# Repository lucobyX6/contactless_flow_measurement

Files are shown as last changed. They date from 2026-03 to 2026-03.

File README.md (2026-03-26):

# Projet recherche 2026 - Capteur de débit d'eau sans contact

Ce projet s'inscrit dans le cursus d'ingénieur ISMIN (_Ingénieur Systèmes Microélectronique et Informatique_). 

## Auteurs
- École des Mines de Saint-Étienne - Étudiant ISMIN : Lucas VINCENT
- École des Mines de Saint-Étienne - Étudiant ISMIN (Double-diplôme) : Reem AL HADDAD

## Contexte

En France, 12% de l'irrigation est réalisée par irrigation gravitaire. Ce procédé repose sur un réseau de canaux de tailles diverses qui distribue l'eau grâce à la différence d'altitude entre l'amont et l'aval. Cette technique ancestrale a notamment permis d'irriguer des terres arides dans le sud de la France, comme la *La Plaine de La Crau*. 

Le dérèglement climatique nous impose de repenser notre utilisation de l’eau. De manière à raisonner son usage et mettre en place les mesures adaptés. Ainsi, il est nécessaire d'établir une surveillance préalable de ces canaux. Pour obtenir le maximum d'informations à l'échelle la plus large possible. Les chercheurs déploient des réseaux de capteurs intelligents le long des cours d'eau.

Traditionnellement, les systèmes employés sont mécaniques et immergés. Cependant, les canaux sont des
milieux à ciel ouvert où transitent une multitude de débris, dont des branches, des feuilles ou des sédiments. Ces perturbations rendent les capteurs immergés peu efficaces, car elles peuvent les bloquer ou les endommager. 

L'alternative actuelle est d'utiliser des capteurs basés sur la technologie radar, entre 10 et 80GHz. Ces derniers sont peu sensibles à la qualité de l'eau ou la présence d'algues et de sédiments. Ils admettent aussi une excellente précision et un faible entretien. Cependant, les objets en surface ou la turbulence des eaux affectent la fiabilité des résultat. De plus, le prix de ces capteurs pouvant atteindre plusieurs milliers d'euros, est un frein à leur déploiement à grande échelle. 

## Capteur `Time-of-flight`

Le projet est une exploration de l'intérêt d'un capteur `Time-of-flight` (TOF) dans l'acquisition du débit d'eau pour les canaux. Ce capteur est équipé d'un émetteur (Tx) et d'un récepteur (Rx). L'émetteur émet un signal infrarouge, qui est réfléchi par la surface, puis retourne dans le récepteur. La carte d'acquisition intégrée analyse la durée entre l'envoi et la réception et à partir de la vitesse de la lumière, constante dans l'air, elle déduit la distance entre le capteur et l'obstacle.     

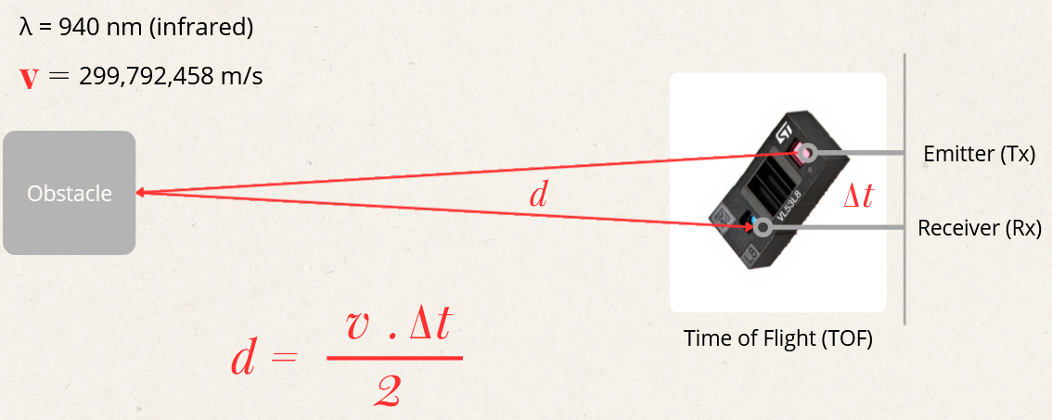
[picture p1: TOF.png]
Illustration of how the time-of-flight sensor works Illustration du fonctionnement du capteur Time-of-flight


Il existe deux types de capteurs `TOF` : 
- Simple : Acquisition d'un unique point.
- Multizone : Acquisition d'une matrice de points.

Nous avons utilisé le `TOF Multizone`, car il permet l'acquisition d'un échantillon de surface, plutôt qu'un unique point.

Sur le papier, il représente une alternative peu coûteuse financièrement et énergétiquement par rapport aux solutions à base de technologies radars actuellement développées. Cependant, nos recherches révèlent que son usage dans le milieu des canaux est **complexe**. 

Ce travail est inspiré de la vidéo [Turn a Time-of-Flight Sensor into a 3D Scanner](https://www.youtube.com/watch?v=s32OUzhjf4U). 

**Matériel utilisé :**
- Carte `Nucleo - STM32 L476RG`
- Capteur TOF Multizone `VL53L5CX` avec module SATEL
- Servomoteur `Microservo 9g`

| Pin | Fonction |
| --- | --- |
| PB9 | SDA - TOF |
| PB8 | SCL - TOF |
| PB0 | LPN - TOF |
| GND | I2C - RST |
| PB0 | LPN - TOF |
| PC0 | PWR_EN - TOF |
| 5V | AVDD |
| 3.3V | IOVDD |
| PB10 | Servo - PWM |

**Documentation :**  \
[1] VL53L8CX Datasheet, ST Microelectronics, 22 December 2022 . [En ligne]. Disponible suivant ce [lien](https://www.st.com/resource/en/datasheet/vl53l8cx.pdf)

[2] SparkFun_VL53L5CX_Library, SparkFun Electronics, No publication date. [En ligne]. Disponible suivant ce [lien](https://github.com/sparkfun/SparkFun_VL53L5CX_Arduino_Library)

[3] NUCLEO-L476RG Pinout, ST Microelectronics, No publication date. [En ligne]. Disponible suivant ce [lien](https://os.mbed.com/platforms/ST-Nucleo-L476RG/#overview)

## Arborescence du projet

Le projet est découpé en deux parties, l'étude de la réflectance de l'eau et l'acquisition et le traitement de données en temps réel. 

- ./0_Water_reflexion : Expériences sur la réflectance de l'eau. 
- ./1_Real_time : Acquisition en temps réel des données du capteurs, traitement et affichage dynamique. 
- ./2_3D_Object : Ensemble des modélisations 3D réalisées en support du projet. 
- ./3_Academic_documents : Rapport et diaporama en anglais détaillant le projet. 

Au vu de la durée du projet, nous avons préféré utiliser `PlatformIO` (similaire à `ArduinoIDE`) plutôt que `STM32 CubeIDE`. Le code est en `C++` et utilise la bibliothèque clef-en-main `SparkFun_VL53L5CX_Library` basée sur la bibliothèque de ST Microelectronics, [x-cube-tof1](https://github.com/STMicroelectronics/x-cube-tof1).  

## Phases du projet

**Phase 1 : Modélisation de la surface de l'eau**

La première approche a été d'essayer de modéliser la surface de l'eau. Le capteur est placé à un peu plus d'un mètre de la surface, de tel sorte que tous ses rayons soient réfléchis exclusivement par l'eau. Toutes les 10ms, il réalise une acquisition qui correpond à un échantillon de la surface de l'eau à l'instant t. En comparant les échantillons, on peut déduire une variation de hauteur et étudier l'aspect de la surface, potentiellement lié à la vitesse de l'eau. 

Malheureusement, nos expériences sur la réflectance de l'eau ont révélé qu'elle ne réfléchissait pas les infrarouges.  

**Phase 2 : Détection d'objets en surface**

L'eau absorbe l'intégralité des rayons infrarouges émis par le capteur. Ainsi, les objets en surface qui sont eux potentiellement réfléchissants peuvent être plus facilement détecté. Cela revient à placer un objet blanc sur une feuille noire. L'étude des mouvements des objets flottants, branches, feuilles et écorces serait une solution pour connaître la vitesse de l'eau en surface (dans un milieu où le vent est négligeable). 

Malheureusement, la précision du capteur décroit avec la distance et la résolution diminue avec l'éloignement. Ces deux phénomènes couplés rendent presque impossible la détection d'un objet à un mètre de distance. 

**Phase 3 : Mise en rotation du capteur**

Pour permettre la détection précise d'objet, il faut obtenir des points d'acquisition plus proche et augmenter leur nombre. L'utilisation de plusieurs capteurs risque de provoquer des interférences optiques qui peuvent impacter la qualité des résultats. La solution la plus simple serait de placer le capteur sur un axe en rotation, à l'aide d'un moteur asservi. Le pas du moteur dicterait alors la résolution. Cette méthode pourrait s'émanciper du capteur multizone 8x8 pour revenir sur un TOF simple.     

Cette phase n'a pas été achevée et reste à approfondir. 

## Conclusions

- L'eau absorbe les ondes infrarouges émisent par le capteur. Cette absorption est d'autant plus présente que le volume d'eau est important. Dans un canal, l'absorption est totale empêchant la prise de mesure à la surface de l'eau. Cette problématique oblige à détecter des objets en surface pour mesurer leur vitesse, plutôt que la surface de l'eau. 

- La résolution du capteur dépend de la distance. La zone d'émission est une pyramide d'angle 45°. Ainsi, plus la distance est importante, plus la distance entre deux points d'aquisition est grande. De plus, la précision décroit avec la distance. Ces deux phénomènes cumulés impactent la capacité à détecter des formes ou un objet à moyenne (1m) ou longue distance (2m). 

- Si le capteur est placé sur un moteur asservi, comme un servomoteur, il peut acquérir un plus grand nombre de points proches les uns des autres. Cette méthode permet d'améliorer la résolution et peut donc potentiellement corriger la problématique identifiée précédemment. 

## Ouverture 

Il existe une technologie similaire au TOF en rotation nommé le LiDAR (light detection and ranging). Ce dernier admet une meilleure résolution, permet une rotation à 360° avec une haute fréquence d'acquisition et est une technologie déjà fortement déployée dans l'industrie, notamment en navigation autonome. 

Cette piste semble donc être une nouvelle voie prometteuse d'analyse. Le capteur pourrait être placé au dessus du canal. Pour obtenir la vitesse de l'eau en surface, il mesurerait la vitesse des feuilles et branchages flottants. Pour mesurer la hauteur d'eau, il étudierait la berge et chercherait un saut de réflectance entre la béton et l'eau.

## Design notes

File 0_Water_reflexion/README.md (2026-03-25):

# Étude de la réflectivité de l'eau

## Organisation du répertoire : 

Le répertoire du projet est constitué de la manière suivante :
- ./0_Programs : Contient l'ensemble des programmes python et C++. 
- ./1_Pictures : Contient les résultats des expériences.
- ./2_Data : Contient les donneés brutes récupérées par durant les expériences. 

## Expériences :

L'objectif de ces expériences est de mesurer la **réflectivité de l'eau** vis à vis du rayon infrarouge émis par le capteur Tof. Deux expériences ont été réalisé, la première a permi de découvrir l'impact du volume d'eau sur la réflectivité et la seconde la réflectivité dans un cas réel, directement sur le canal. 

Le code `Mean_on_reflectance_calculation.cpp` est le code envoyé dans le carte *STM32 L476RG* pour la première expérience. Il suffit pour l'utiliser de copier son contenu dans le fichier `main.cpp` de votre projet.    

La seconde expérience nécessite l'usage du code `Mean_on_distance_calculation.cpp`.

### Expérience 1 - Test de réflectivité dans un récipient

L'objectif de cette expérience est d'obtenir un premier aperçu de la variation de réflectivité induite par l'eau, en fonction du volume. Pour la réaliser, le capteur a été positionné verticalement au dessus d'un récipient rempli d'eau, de tel sorte que les rayons lumineux se disperse le moins possible et atteignent tous la surface de l'eau.   

**Choix du récipient :**

Le premier récipient utilisé était une casserole pour sa praticité d'usage et son volume. Cependant, le capteur renvoyait des valeurs étrangements faible, peu importe la quantité d'eau. Après comparaison avec un récipient en verre, il s'est avéré que la casserole fonctionnait comme un guide d'ondes pour les rayons infrarouges. Pour écarter ce problème, l'expérience a été réalisée avec un bol en verre. 

**Acquisition :**

La carte électronique génère au bout d'une dizaine de secondes une liste de 64 valeurs.  Chaque valeur est la moyenne des résultats pour un point d'acquisition sur 10s. Les résultats sont stockées dans le dossier `./2_Data`.   

**Résultats :**

Les résultats précédents sont traités par le programme python `E1_display_water_reflexion_results.py`. Ce dernier génère à partir de ces données des matrices. Elles sont stockées dans le dossier `./1_Pictures` avec le préfixe `E1_`. Chaque carré est une cellule d'acquisition du récepteur.   

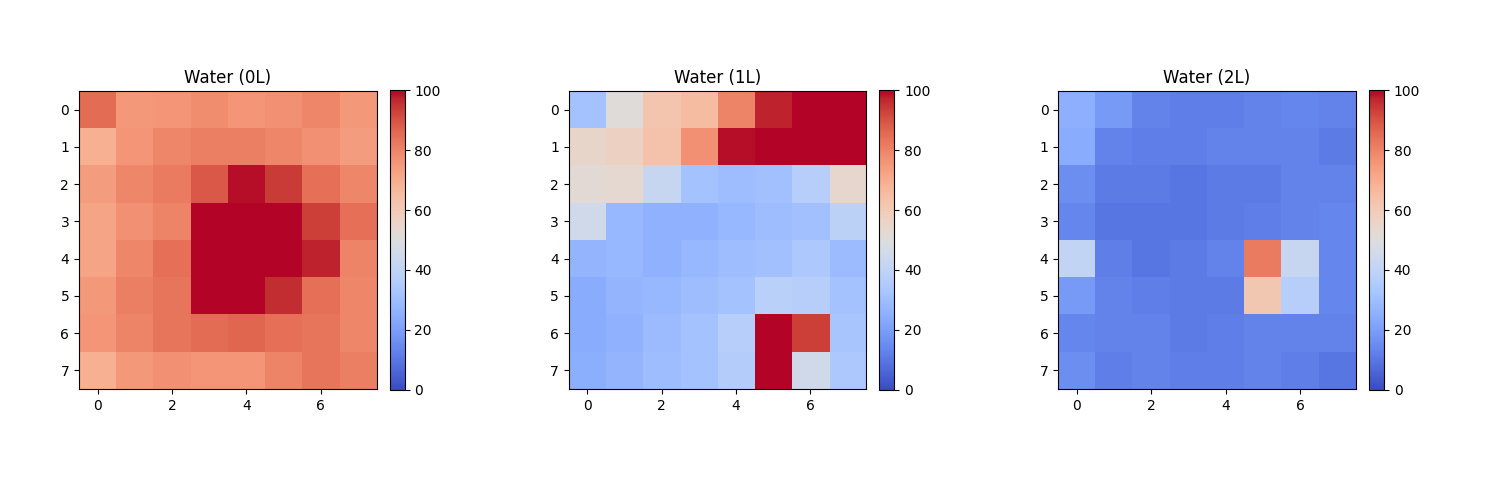
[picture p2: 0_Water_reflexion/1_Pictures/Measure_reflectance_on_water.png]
Results of the reflectivity measurement experiment for 0L, 1L and 2L of water in the container. Résultats de l'expérience de mesure de la réflectivité pour 0L, 1L et 2L d'eau dans le récipient.


La réflectance s'exprime en pourcentage et représente la part d'énergie qui a été réfléchie par la surface et qui est retournée vers la cellule d'acquisition. On remarque qu'**initialement**, la **réflectance est quasi-totale**. Néanmoins, dès qu'on **ajoute de l'eau** cette dernière chute jusqu'à être **quasiment nulle**.   

_Données associées :_ 
- reflectance_0.5L_waveguide_issue.txt
- reflectance_2L_waveguide_issue.txt
- reflectance_4L_waveguide_issue.txt
- reflectance_no_water.txt
- reflectance_1L.txt
- reflectance_2L.txt

### Expérience 2 - Test de réflectivité dans le canal

**Environnement de test :**

Les résultats de l'expérience précédente ont révélé que plus il y avait d'eau, plus la réflectivité était faible. Cette deuxième expérience vise à étudier la réflectance en milieu réel. Elle a été réalisé sur le **Canal de Provence** ([43.441339, 5.488827](https://www.openstreetmap.org/search?lat=43.441339&lon=5.488827&zoom=19#map=19/43.441339/5.488827)) à proximité de l'école. 

Le capteur a été disposé sur l'une des berges, tête en direction de l'eau. Il était à moins d'un mètre de la surface. La mesure a permi d'établir la matrice suivante. 

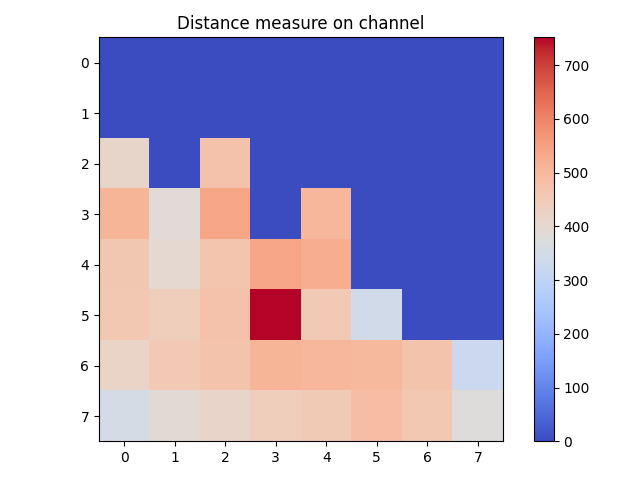
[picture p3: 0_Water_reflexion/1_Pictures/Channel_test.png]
Results of the measurement experiment on the channel. Résultat de l'expérience de mesure sur le canal.


Les résultats sont traités par le programme python `E2_test_on_channel.py`.

**Observations :**

La moitié des rayons, ici la partie basse de l'image, se sont réfléchis sur le parapet en béton du canal. La réflectance a été suffisante pour qu'ils renvoient une distance chiffrée. La seconde partie des rayons se sont réfléchis sur l'eau. Le capteur a transmis pour chacune de ces positions, une valeur 0. 

Ce comportement a lieu si aucun rayon ne revient en direction du capteur, car la surface est trop lointaine, ou dans le cas, où la réflectance est nulle. Dans le cas de cette expérience, le capteur est à moins d'un mètre de la surface acqueuse. Ainsi, l'eau a absorbé tous les rayons.

_Données associées :_ 
- channel_water_test.txt
- sky_test.txt

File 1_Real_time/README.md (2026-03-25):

# Acquisition et traitement des données du capteur en temps réel

## Organisation du répertoire : 

Le répertoire du projet est constitué de la manière suivante :

. \
├── 0_Static : Contient les pré-codes pour tester les fonctionnalités sur des données statiques avant l'implémentation dynamique. \
│   ├── 0_Programs : Algorithme C++ et Python \
│   ├── 1_Data : Données récoltées pour tester les foncionnalités \
│   └── 2_Pictures : Matrices résultats. \
├── 1_Dynamic : Contient les codes d'acquisition et de traitement en temps réel. \
│   ├── 0_Without_obj_detect : Acquisition en temps réel et affichage sans traitement dans une matrice 3D. \
│   ├── 1_With_obj_detect : Acquisition en temps réel, identification des objets puis affichage dans une matrice 3D. \
│   ├── 2_With_distances_between_points : Acquisition en temps réel, identification des objets puis affichage dans une matrice 3D en prenant en considération la résolution. \
│   └── 3_With_rotation : Acquisition en temps réel, identification des objets puis affichage dans une matrice 3D avec la rotation autour d'un axe.

## Section statique

**Algorithmes :**
- `print_values.py` : Lit le fichier de données et affiche les valeurs dans une matrice 8x8.  
- `detect_object.py` : Détecte les objets présents dans les données à l'aide d'une heuristique. 
- `detect_movement.py` : Détecte les objets et leur barycentre à l'aide d'une heuristique.  

Le code `get_mean_distances.cpp` est le code envoyé dans le carte *STM32 L476RG* pour récupérer les données nécesaires aux algorithmes de la section. Il suffit pour l'utiliser de copier son contenu dans le fichier `main.cpp` de votre projet. 

**L'impact de la distance sur la résolution :**

Les nouvelles fonctionnalités, comme l'affichage 3D et la détection d'objets sont initialement développées et testés sur des données que nous avons récoltés. Le dossier `Distance_problem` contient les mesures receuillies à différentes distances d'objets. L'objectif était d'étudier l'impact de la résolution sur la détection. 

Plus l'objet **est lointain**, plus **la résolution est faible**, car la zone d'émission est plus grande, ce qui peut être assimilé à un écartement des points d'acquisition.  

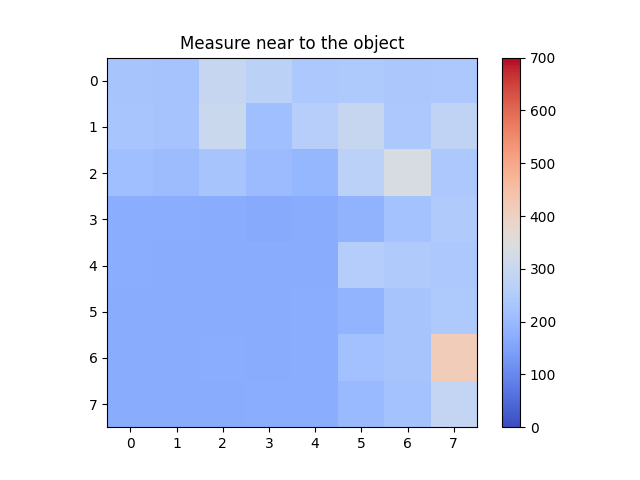
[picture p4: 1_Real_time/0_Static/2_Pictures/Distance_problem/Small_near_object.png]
Measure near to the objet at 20cm away. Mesure d'un objet à une vingtaine de centimètres.


Cette première capture réalisée à une vingtaine de centimètres de l'objet. On y détecte aisément la forme de l'objet de la cellule 3,0 à la cellule 7,4.  

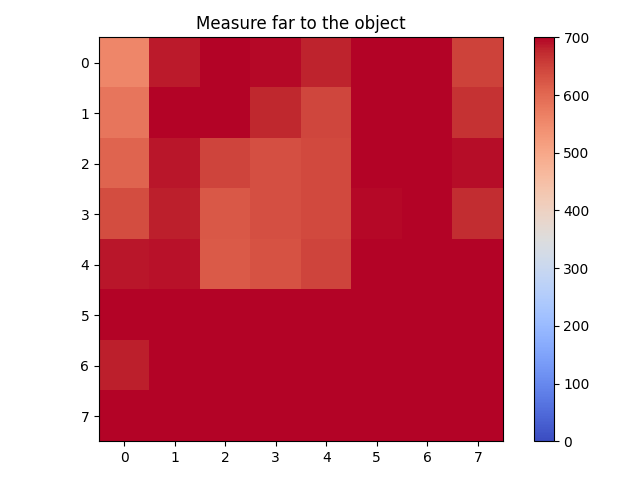
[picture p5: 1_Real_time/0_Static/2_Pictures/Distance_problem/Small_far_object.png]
Measure far to the objet at 1m away. Mesure d'un objet à un peu plus d'un mètre.


Néanmoins, sur cette seconde illustration prise à un peu plus d'un mètre de l'objet, il est impossible de le détecter. 

Le dossier `Objects_movement` contient les données pour la détection d'objets et de barycentre. Initialement, l'algorithme récupère les valeurs brutes de distances (voir première image). À partir d'une heuristique simple, il détecte pour chaque point ses voisins et lui attribue une valeur. Cette valeur désigne son groupe potentiel. Les groupes sont ensuite affichés avec des couleurs (voir deuxième image). Un autre algorithme basé sur la même heuristique calcule le barycentre de chacun de ces groupes. En comparant la position des barycentres pour deux captures proches, on peut déduire la vitesse de l'objet.    

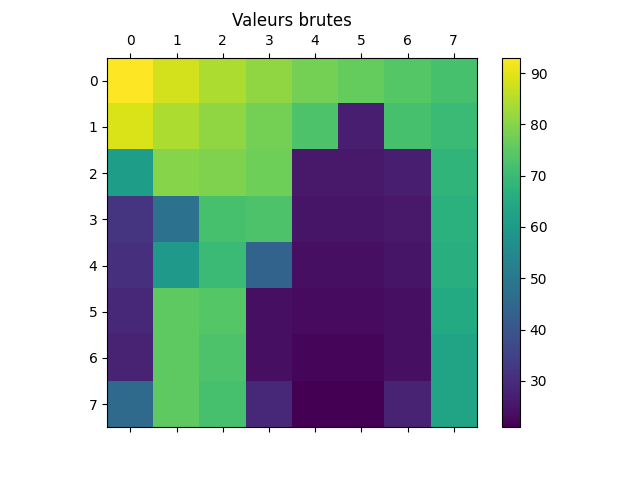
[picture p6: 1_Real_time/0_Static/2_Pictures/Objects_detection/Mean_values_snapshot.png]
Intial value calculated by sensor. Valeur initialement récupérée par le capteur.


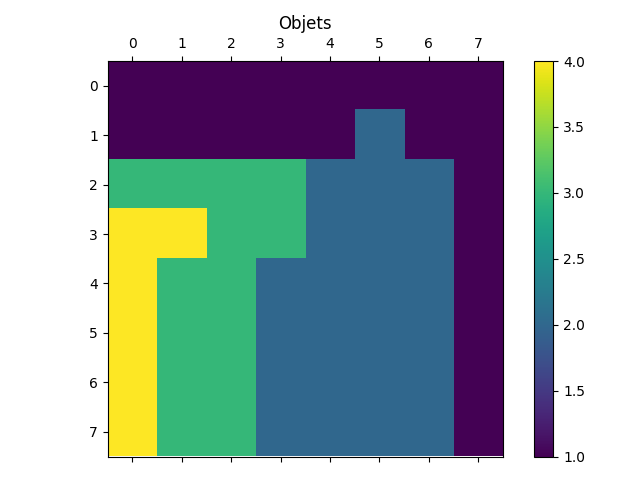
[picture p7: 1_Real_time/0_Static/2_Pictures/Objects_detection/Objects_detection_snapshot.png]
Calculated groups by the algorithm. Groupes calculés par l'algorithme.


## Section dynamique

Cette section est l'application sur un flux de données temps réel des opérations de la section statique. Chaque algorithme `C++` renvoit les valeurs nécessaires à l'algorithme `Python` lié. Cet algorithme affiche les valeurs dynamiquement dans une matrice 3D. L'échelle est en milimètre pour l'axe z et en identifiant de cellules pour l'axe x et y (sauf à partir du dossier `/2_With_distances_between_points`).  

**Dossiers :**
- ./0_Without_obj_detect : Récupération des données de la `carte ST L476RG`, réflectances ou distances et affichage en 3D. 
- ./1_With_obj_detect :  Récupération des données (distances mesurées) de la `carte ST L476RG`, traitement pour détecter les objets et affichage en 3D.  
- ./2_With_distances_between_points : Récupération des données (distances mesurées), traitement pour détecter les objets et affichage en prenant en considération la distance entre les points d'acquisition (répartition homogène).   
- ./3_With_rotation : Identique à précédemment, mais à l'aide d'une matrice de rotation le capteur tourne dans l'espace. 

**Cas particulier de `1_With_obj_detect` :**

Pour utiliser le code Python `real_time_display_obj.py`, il convient d'utiliser le code C++ `real_time_acquisition.cpp` du dossier précédent. Le code C++ `3D_with_detection_objects.cpp` est une convertion du code Python en C++ pour détecter les objets directement sur la carte sans nécessiter un ordinateur. Le code Python `real_time_display_obj_from_C.py` permet d'afficher les résultats de ce code C++.   

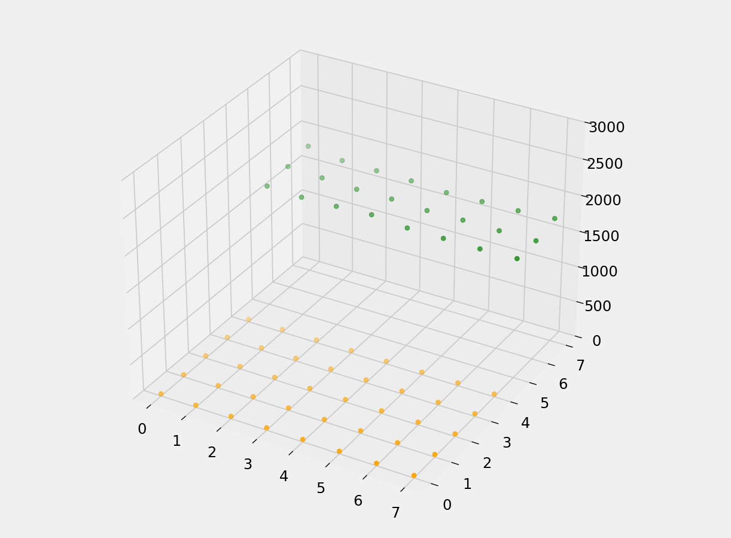
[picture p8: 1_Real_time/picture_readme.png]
Object detection result and 3D display Résultat de la détection d'objet et affichage dans l'espace


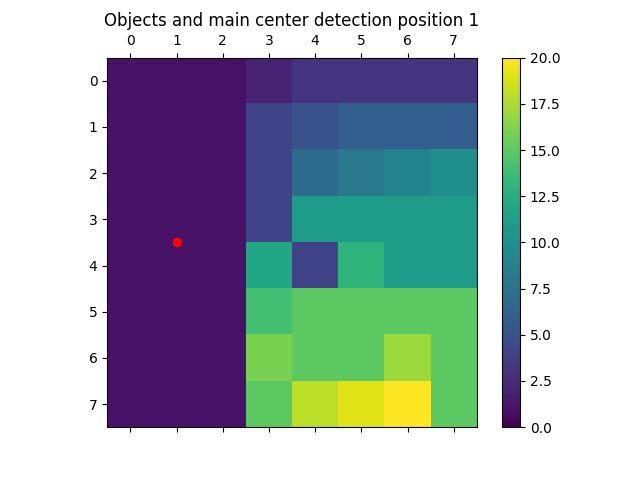
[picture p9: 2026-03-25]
1_Real_time/0_Static/2_Pictures/Objects_movement/move_pos1.png

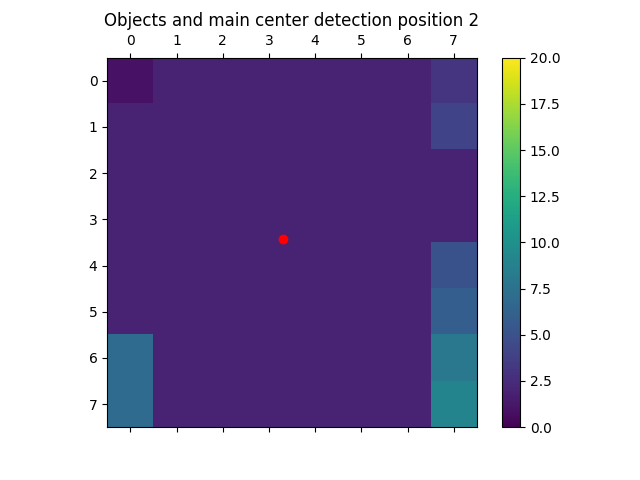
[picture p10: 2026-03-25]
1_Real_time/0_Static/2_Pictures/Objects_movement/move_pos2.png

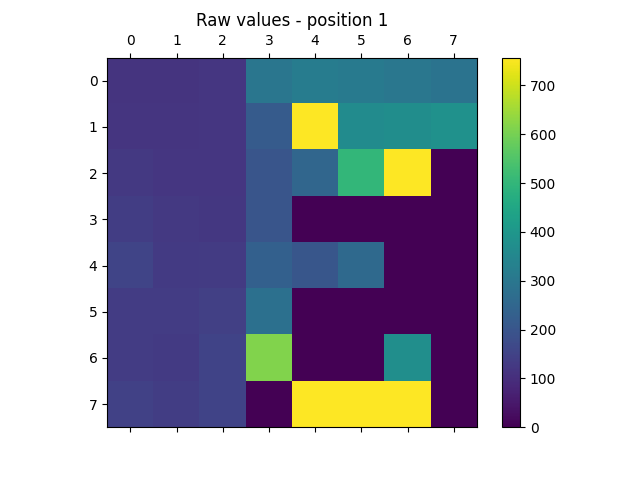
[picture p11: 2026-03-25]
1_Real_time/0_Static/2_Pictures/Objects_movement/raw_pos1.png

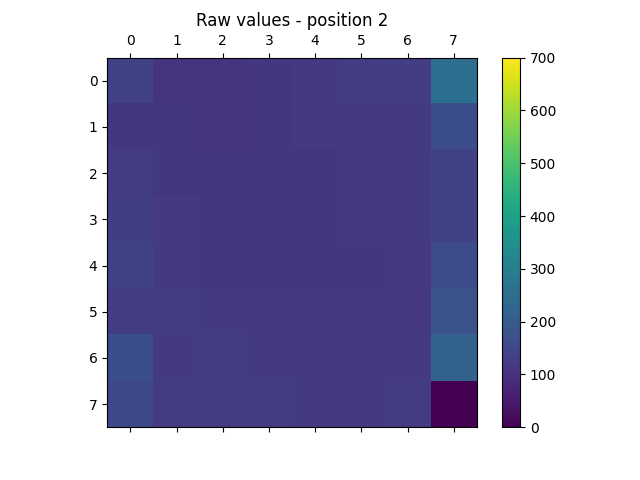
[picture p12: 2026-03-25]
1_Real_time/0_Static/2_Pictures/Objects_movement/raw_pos2.png

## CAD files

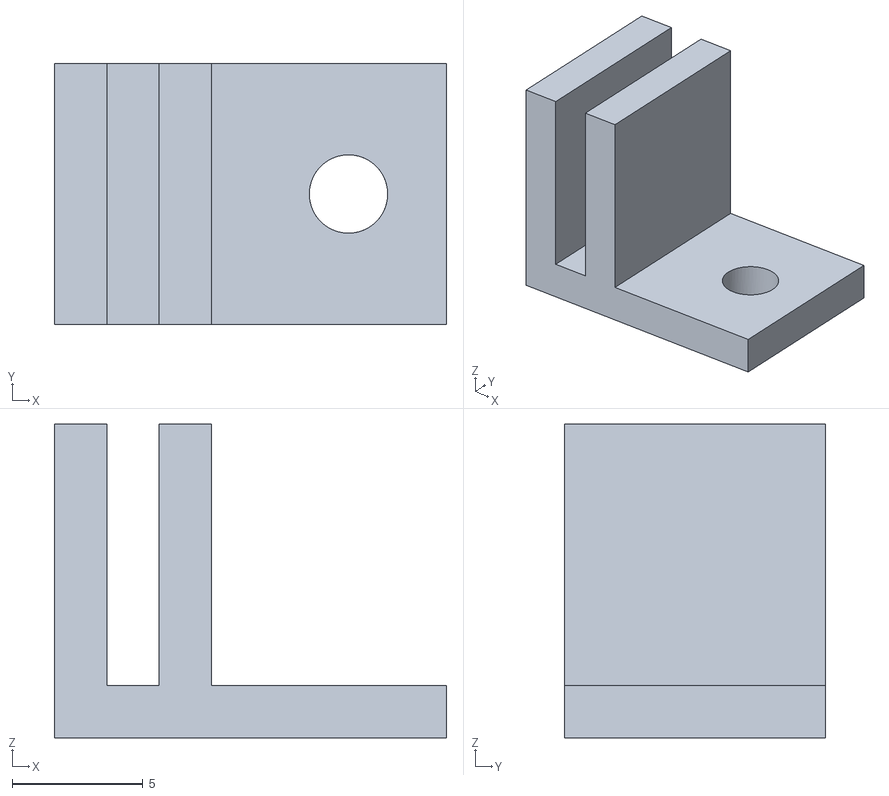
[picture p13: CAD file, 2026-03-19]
2_3D_Object/STL/TOF_holder.stl
15.0 x 10.0 x 12.0

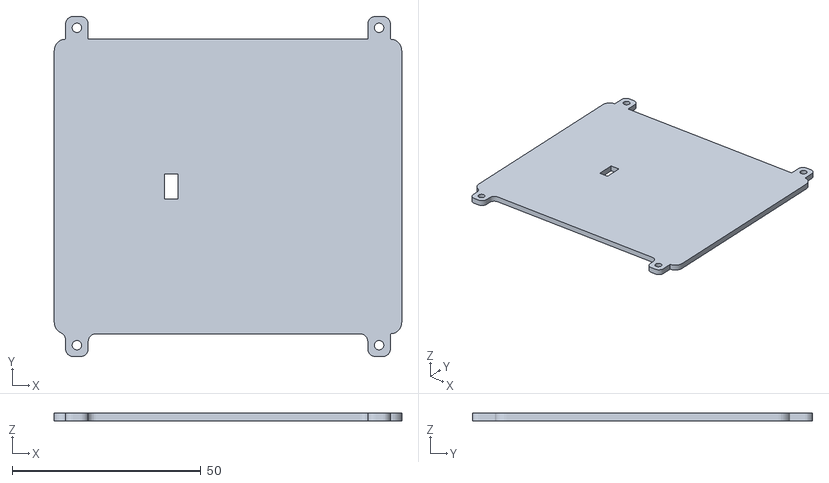
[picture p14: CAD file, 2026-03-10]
2_3D_Object/STL/TOF_Box_base.stl
92.0 x 90.0 x 2.00

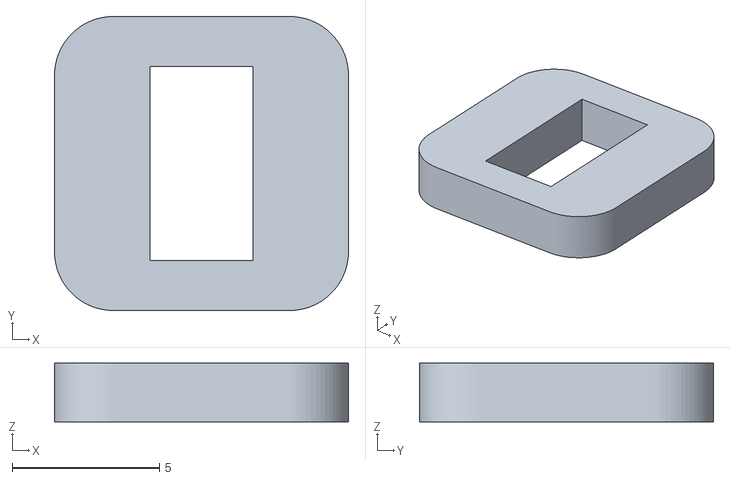
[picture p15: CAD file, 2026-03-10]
2_3D_Object/STL/Test_TOF_hole.stl
10.0 x 10.0 x 2.00

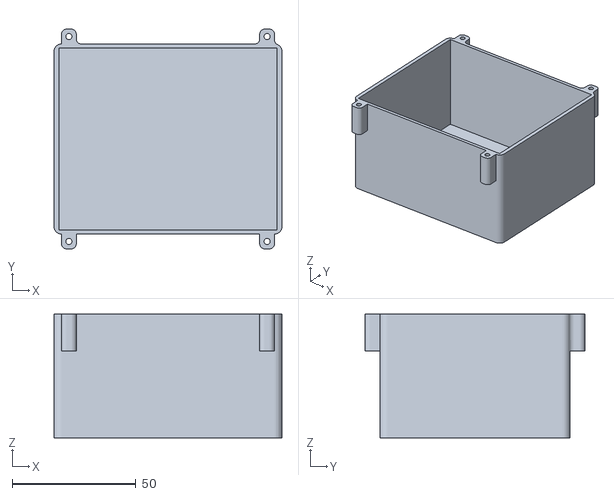
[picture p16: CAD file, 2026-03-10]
2_3D_Object/STL/STM32_Box_base.stl
92.0 x 88.7 x 50.0

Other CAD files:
2_3D_Object/IPT/OldVersions/TOF_holder.0001.ipt
2_3D_Object/IPT/STM32_Box_base.ipt
2_3D_Object/IPT/TOF_Box_base.ipt
2_3D_Object/IPT/TOF_holder.ipt
2_3D_Object/IPT/Test_TOF_hole.ipt

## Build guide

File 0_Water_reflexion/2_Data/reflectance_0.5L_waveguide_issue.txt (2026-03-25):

0, 0: 4
0, 1: 4
0, 2: 6
0, 3: 3
0, 4: 5
0, 5: 3
0, 6: 6
0, 7: 6
1, 0: 5
1, 1: 5
1, 2: 4
1, 3: 3
1, 4: 3
1, 5: 2
1, 6: 4
1, 7: 6
2, 0: 52
2, 1: 6
2, 2: 7
2, 3: 3
2, 4: 3
2, 5: 5
2, 6: 4
2, 7: 6
3, 0: 82
3, 1: 6
3, 2: 5
3, 3: 3
3, 4: 2
3, 5: 2
3, 6: 5
3, 7: 5
4, 0: 5
4, 1: 5
4, 2: 4
4, 3: 3
4, 4: 5
4, 5: 3
4, 6: 4
4, 7: 8
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

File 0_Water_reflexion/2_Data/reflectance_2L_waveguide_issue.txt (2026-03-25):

0, 0: 1
0, 1: 3
0, 2: 2
0, 3: 2
0, 4: 2
0, 5: 2
0, 6: 2
0, 7: 2
1, 0: 1
1, 1: 2
1, 2: 2
1, 3: 2
1, 4: 2
1, 5: 2
1, 6: 2
1, 7: 5
2, 0: 1
2, 1: 2
2, 2: 2
2, 3: 2
2, 4: 3
2, 5: 3
2, 6: 6
2, 7: 2
3, 0: 1
3, 1: 2
3, 2: 2
3, 3: 2
3, 4: 19
3, 5: 49
3, 6: 3
3, 7: 2
4, 0: 1
4, 1: 4
4, 2: 2
4, 3: 2
4, 4: 3
4, 5: 69
4, 6: 8
4, 7: 3
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

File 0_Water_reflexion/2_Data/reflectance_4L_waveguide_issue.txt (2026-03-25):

0, 0: 0
0, 1: 0
0, 2: 0
0, 3: 0
0, 4: 0
0, 5: 0
0, 6: 0
0, 7: 11
1, 0: 1
1, 1: 1
1, 2: 3
1, 3: 1
1, 4: 0
1, 5: 0
1, 6: 0
1, 7: 0
2, 0: 32
2, 1: 11
2, 2: 1
2, 3: 1
2, 4: 0
2, 5: 0
2, 6: 2
2, 7: 0
3, 0: 73
3, 1: 2
3, 2: 1
3, 3: 0
3, 4: 0
3, 5: 0
3, 6: 0
3, 7: 0
4, 0: 1
4, 1: 3
4, 2: 1
4, 3: 0
4, 4: 0
4, 5: 0
4, 6: 0
4, 7: 3
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

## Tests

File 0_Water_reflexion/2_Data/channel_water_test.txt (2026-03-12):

0, 0: 0
0, 1: 0
0, 2: 0
0, 3: 0
0, 4: 0
0, 5: 0
0, 6: 0
0, 7: 0
1, 0: 0
1, 1: 0
1, 2: 0
1, 3: 0
1, 4: 0
1, 5: 0
1, 6: 0
1, 7: 0
2, 0: 413
2, 1: 0
2, 2: 475
2, 3: 0
2, 4: 0
2, 5: 0
2, 6: 0
2, 7: 0
3, 0: 506
3, 1: 388
3, 2: 539
3, 3: 0
3, 4: 500
3, 5: 0
3, 6: 0
3, 7: 0
4, 0: 461
4, 1: 399
4, 2: 466
4, 3: 538
4, 4: 525
4, 5: 0
4, 6: 0
4, 7: 0
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

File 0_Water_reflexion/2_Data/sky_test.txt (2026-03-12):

0, 0: 0
 0, 1: 0
 0, 2: 0
 0, 3: 0
 0, 4: 0
 0, 5: 0
 0, 6: 0
 0, 7: 0
 1, 0: 0
 1, 1: 0
 1, 2: 0
 1, 3: 0
 1, 4: 0
 1, 5: 0
 1, 6: 0
 1, 7: 0
 2, 0: 0
 2, 1: 0
 2, 2: 0
 2, 3: 0
 2, 4: 0
 2, 5: 0
 2, 6: 0
 2, 7: 0
 3, 0: 0
 3, 1: 0
 3, 2: 0
 3, 3: 0
 3, 4: 0
 3, 5: 0
 3, 6: 0
 3, 7: 0
 4, 0: 0
 4, 1: 0
 4, 2: 0
 4, 3: 0
 4, 4: 0
 4, 5: 0
 4, 6: 0
 4, 7: 0
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

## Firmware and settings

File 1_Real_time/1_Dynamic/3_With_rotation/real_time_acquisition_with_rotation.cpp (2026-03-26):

#include <Wire.h>
#include <SparkFun_VL53L5CX_Library.h>
#include <Servo.h>

// Pin definitions
#define SDA_PIN PB9
#define SCl_PIN PB8
#define LPN_PIN PB0
#define PWR_EN_PIN PC0
#define PWM_SERVO_PIN PB10

// VL53L5CX ToF sensor instance
SparkFun_VL53L5CX sensor;
VL53L5CX_ResultsData measurementData;

// DF9GMS servo motor instance
Servo servo_tof;

// I2C speed - use 1MHz for fast data transfer
#define I2C_SPEED 1000000

// Angle °
int angle =0;
int direction =1;

void setup() {
  Serial.begin(115200); // COM 115200 bauds
  delay(3000); // Waiting for serial monitor

  Serial.println("[INFO] Initializing pins");

  // Enable power by setting PWR_EN HIGH 
  pinMode(PWR_EN_PIN, OUTPUT);
  digitalWrite(PWR_EN_PIN, HIGH);
  delay(10);

  // Enable I2C on sensor by setting LPn HIGH
  pinMode(LPN_PIN, OUTPUT);
  digitalWrite(LPN_PIN, HIGH);
  delay(10);

  // Servomotor
  servo_tof.attach(PWM_SERVO_PIN); 
  Serial.println("[INFO] Servo ready");

  // Initialize I2C with specified pins and speed
  Wire.begin();
  Wire.setClock(I2C_SPEED);

  Serial.println("[INFO] I2C ready");

  // Initialize sensor
  if (!sensor.begin()) {
    Serial.println("[ERROR] Sensor init failed");
    while (1) {
      delay(100);
    }
  }

  Serial.println("[INFO] Sensor online");

  // Configure sensor for 8x8 resolution
  sensor.setResolution(64);  // 64 zones = 8x8

  // Set ranging frequency to 15Hz (stable for continuous streaming)
  sensor.setRangingFrequency(15);

  // Start ranging
  sensor.startRanging();

  Serial.println("[INFO] Resolution 8x8 and 15kHz frequency");

  Serial.println("[INFO] Start communication");
}

void loop() {

  Serial.printf("start\n");

  // Check if new ToF data is available
  if (sensor.isDataReady()) {
    if (sensor.getRangingData(&measurementData)) {
      Serial.printf("%d\n", angle);
      // Send all value using serial port
      for (int row = 0; row < 8; row++) 
      {
        for (int col = 0; col < 8; col++) 
        {
          int index = row * 8 + col;

          Serial.printf("%d, %d, %d\n", row, col, measurementData.distance_mm[index]);
        }
      }
    }
  }  
  Serial.printf("end\n");

  // Small delay to prevent overwhelming the serial buffer
  delay(50);

  angle = angle + direction;
  servo_tof.write(angle);  
  if(angle >= 180)
  {
    direction = -1;
  }
  if(angle <= 0)
  {
    direction = 1;
  }
}

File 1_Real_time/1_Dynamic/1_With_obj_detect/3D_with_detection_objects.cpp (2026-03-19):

/* - - - Librairies - - - */
#include <Wire.h>
#include <SparkFun_VL53L5CX_Library.h>

// Pin definitions
#define SDA_PIN PB9
#define SCl_PIN PB8
#define LPN_PIN PB0
#define PWR_EN_PIN PC0

// VL53L5CX ToF sensor instance
SparkFun_VL53L5CX sensor;
VL53L5CX_ResultsData measurementData;

// I2C speed - use 1MHz for fast data transfer
#define I2C_SPEED 1000000

// Objects identification variables
int matrice[8][8]; // Distances between sensor and objects
int matrice_objects[8][8]; // Approximation of the membership object

int diff[3][3]; // Neighborhood evaluation
int value = 0; // Temporary value

int threshold = 100; // Threshold to be a neighbor of same group
int group = 1; // group counter

bool find = false; // No group find in neighborhood


/* - - - Prototypes - - - */
int abs(int entry);

/* - - - One time at start - - - */
void setup() {
  Serial.begin(115200); // COM 115200 bauds
  delay(3000); // Waiting for serial monitor

  Serial.println("[INFO] Initializing pins");

  // Enable power by setting PWR_EN HIGH 
  pinMode(PWR_EN_PIN, OUTPUT);
  digitalWrite(PWR_EN_PIN, HIGH);
  delay(10);

  // Enable I2C on sensor by setting LPn HIGH
  pinMode(LPN_PIN, OUTPUT);
  digitalWrite(LPN_PIN, HIGH);
  delay(10);

  // Initialize I2C with specified pins and speed
  Wire.begin();
  Wire.setClock(I2C_SPEED);

  Serial.println("[INFO] I2C ready");

  // Initialize sensor
  if (!sensor.begin()) {
    Serial.println("[ERROR] Sensor init failed");
    while (1) {
      delay(100);
    }
  }

  Serial.println("[INFO] Sensor online");

  // Configure sensor for 8x8 resolution
  sensor.setResolution(64);  // 64 zones = 8x8

  // Set ranging frequency to 15Hz (stable for continuous streaming)
  sensor.setRangingFrequency(15);

  // Start ranging
  sensor.startRanging();

  Serial.println("[INFO] Resolution 8x8 and 15kHz frequency");

  Serial.println("[INFO] Start acquisition");

  for (int row = 0; row < 8; row++) 
  {
    for (int col = 0; col < 8; col++) 
    {
      matrice[row][col] = 0;
      matrice_objects[row][col] = 0;
      if(row < 3 && col < 3)
      {
        diff[row][col] = 0;
      }
    }
  }
}

/* - - - Infinity loop - - - */
void loop() {

  
  // Check if new ToF data is available
  if (sensor.isDataReady()) {
    if (sensor.getRangingData(&measurementData)) {

      // Get distances values
      for (int row = 0; row < 8; row++) 
      {
        for (int col = 0; col < 8; col++) 
        {
          int index = row * 8 + col;

          matrice[row][col] = measurementData.distance_mm[index];
        }
      }
    }
  }  

  // Estimate group
  for (int row = 0; row < 8; row++) 
  {
    for (int col = 0; col < 8; col++) 
    {
      
      // Calculate distances with neighborhood
      if(row-1 < 0 || col-1 < 0)
        diff[0][0] = 9999;
      else
        diff[0][0] = abs(matrice[row][col] - matrice[row-1][col-1]);

      if(row-1 < 0)
          diff[0][1] = 9999;
      else
          diff[0][1] = abs(matrice[row][col] - matrice[row-1][col]);

      if(row-1 < 0 or col+1 > 7)
          diff[0][2] = 9999;
      else
          diff[0][2] = abs(matrice[row][col] - matrice[row-1][col+1]);

      if(col-1 < 0)
          diff[1][0] = 9999;
      else
          diff[1][0] = abs(matrice[row][col] - matrice[row][col-1]);

      diff[1][1] = -1;

      if(col+1 > 7)
          diff[1][2] = 9999;
      else
          diff[1][2] = abs(matrice[row][col] - matrice[row][col+1]);

      if(row+1 > 7 or col-1 < 0)
          diff[2][0] = 9999;
      else
          diff[2][0] = abs(matrice[row][col] - matrice[row+1][col-1]);

      if(row+1 > 7)
          diff[2][1] = 9999;
      else
          diff[2][1] = abs(matrice[row][col] - matrice[row+1][col]);

      if(row+1 > 7 or col+1 > 7)
          diff[2][2] = 9999;
      else
          diff[2][2] = abs(matrice[row][col] - matrice[row+1][col+1]);
    
      // If two points have proximity, one of this point already have a group ? 
      for (int i = 0; i < 3; i++) 
      {
        for (int j = 0; j < 3; j++) 
        {
          value = diff[i][j];
          if((value != 9999 && value !=-1) && value < threshold) 
          {
            if(matrice_objects[row+i-1][col+j-1] !=0)
            {
              matrice_objects[row][col] = matrice_objects[row+i-1][col+j-1];
              find = true;
            }
              
          }  
          
        }
      }

      // If no ... so we choose an arbitrary group
      if(find == false)
      { 
        matrice_objects[row][col] = group;
        group ++;
      }
      else
      {
        find = false;
      }
    }
  }

  // Restart values for next acquisition
  find = false;
  group = 1;

  // Send values using serialport
  Serial.printf("start\n");
  for (int row = 0; row < 8; row++) 
  {
    for (int col = 0; col < 8; col++) 
    {
      if(row != 7 || col != 7)
        Serial.printf("%d,%d,", matrice[row][col], matrice_objects[row][col]);
      else
        Serial.printf("%d,%d", matrice[row][col], matrice_objects[row][col]);
    
      matrice[row][col] = 0;
      matrice_objects[row][col] = 0;
      
      if(row < 3 && col < 3)
      {
        diff[row][col] = 0;
      }
    
    }

  } 
  Serial.printf("\nend\n");

  // Small delay to prevent overwhelming the serial buffer
  delay(50);
}

/* - - - Function - - - */
int abs(int entry)
{
  if(entry < 0)
    return -entry;
  else
    return entry;
}
